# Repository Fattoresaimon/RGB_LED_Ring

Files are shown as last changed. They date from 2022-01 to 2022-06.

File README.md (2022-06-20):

# RGB LED Ring
### This is the official repository of the RGB LED Ring!
### Available on my [DuPPa Store!](https://www.duppa.net/shop/rgb-led-ring/) or [Tindie](https://www.tindie.com/products/saimon/rgb-led-ring-v11/)!

The RGB LED Ring is an accessory of the rotary encoder.
The shaft  of the encoder can be insert in the center hole of the board. It support both the normal rotary encoder and the RGB encoder.

There are 48 RGB LED disposed in a circle with a 40mm diameter. In total there are 144 LEDs.
Each single LED can be controller with 256 step, then each RGB LED are encoded with the 888 format.
The controller is the [ IS31FL3745](https://www.lumissil.com/assets/pdf/core/IS31FL3745_DS.pdf)

In this repository you can find:
- [Schematic](/PDF/)
- [Gerbers](/Hardware/Gerber/)
- [BOM](/Hardware/BOM/)
- [Pick & Place](/Hardware/Pick%20Place/)
- [3D File](/Hardware/ExportSTEP/)

[Here you can find the Arduino library](https://github.com/Fattoresaimon/ArduinoDuPPaLib)

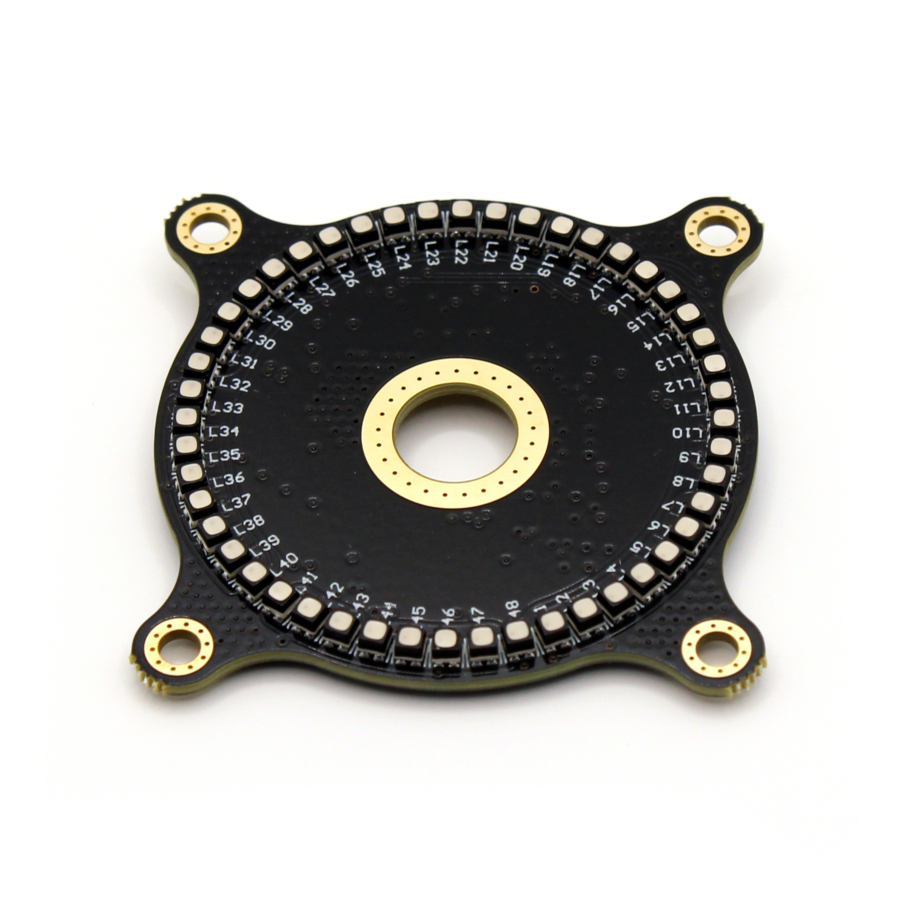
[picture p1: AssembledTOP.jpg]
Assembled


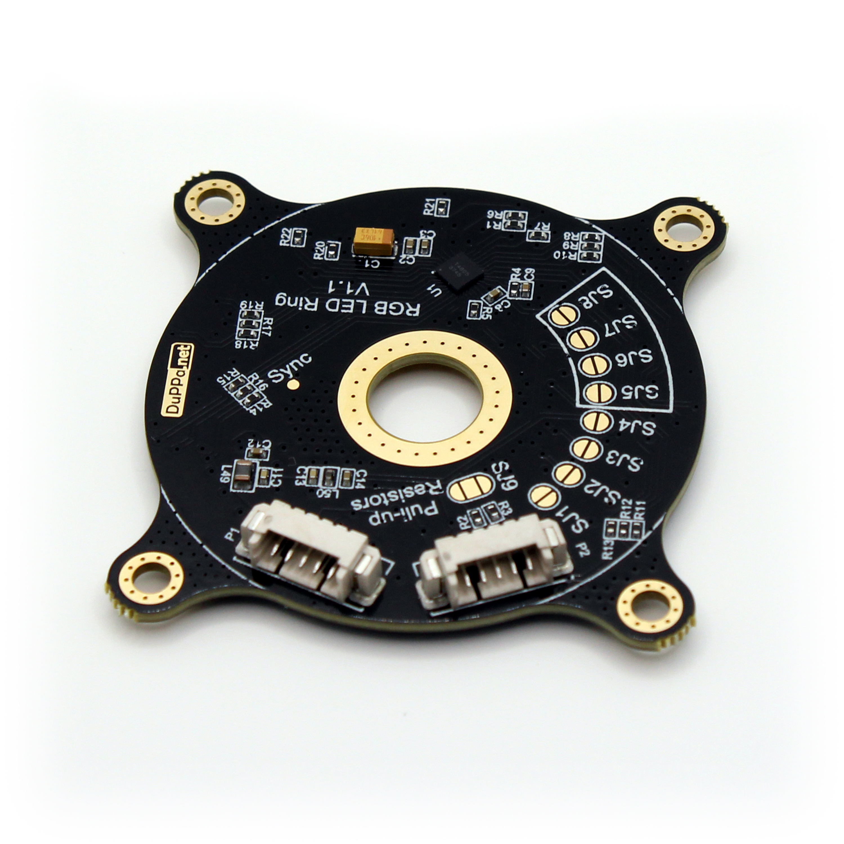
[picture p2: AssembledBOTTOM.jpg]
Bottom


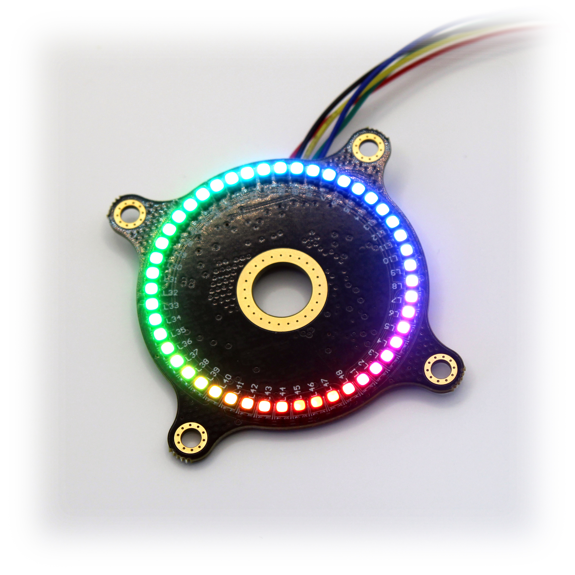
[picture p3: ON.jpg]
ON


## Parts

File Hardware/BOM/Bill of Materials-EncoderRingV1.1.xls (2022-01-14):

Comment | Designator | Footprint | Quantity | Voltage | Value | PartNumber
Tantalum Case-A | C1 | SMC_A | 1 | 16V | 10u | CA45-A016K106T
C-EUC0402 | C2, C8 | C0402 | 2 | 16V | 470n | CL05A474KA5NNNC
C-EUC0402 | C3, C9, C12, C14 | C0402 | 4 | 16V | 100n | CL05B104KO5NNNC
C-EUC0402 | C11, C13 | C0402 | 2 | 16V | 10n | CL05B103KA5NNNC
RGB_2020_NH-Z1921RGBA-SG | L1, L2, L3, L4, L5, L6, L7, L8, L9, L10, L11, L12, L13, L14, L15, L16, L17, L18, L19, L20, L21, L22, L23, L24, L25, L26, L27, L28, L29, L30, L31, L32, L33, L34, L35, L36, L37, L38, L39, L40, L41, L42, L43, L44, L45, L46, L47, L48 | RGB_2121_NH-Z1921RGBA-SG | 48 |  |  | NH-Z1921RGBA-SG
600R@100MHz | L49 | L0805 | 1 |  |  | CBW201209U601T
600R@100MHz | L50 | L0402 | 1 |  |  | CBG100505U601T
Header 5HSMD | P1, P2 | MOLX-52361-0571-5_V | 2 |  |  | C22076
R-EU_R0402 | R1, R8, R11, R14, R17, R20 | R0402 | 6 |  | 51r | RC0402JR-0751RL
R-EU_R0402 | R2, R3, R4 | R0402 | 3 |  | 4k7 | 0402WGJ0472TCE
R-EU_R0402 | R5 | R0402 | 1 |  | 10k | RC-02W1002FT
R-EU_R0402 | R6, R7, R9, R10, R12, R13, R15, R16, R18, R19, R21, R22 | R0402 | 12 |  | 20r | RC0402JR-0720RL
TestPoint Trough Hole | Sync | PAD_1mm | 1 |  |  | RS-200-208
IS31FL3745 | U1 | BGA36C50P6X6_290X290X40 | 1 |  |  | IS31FL3745

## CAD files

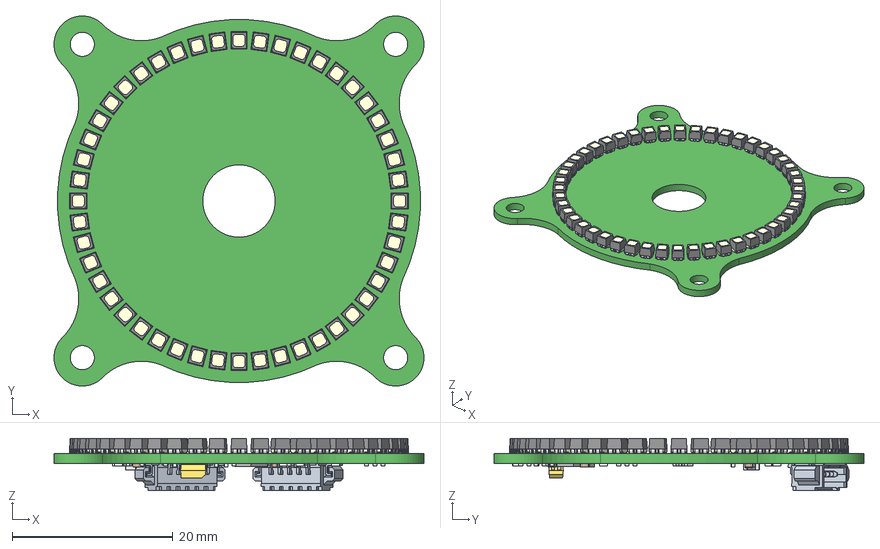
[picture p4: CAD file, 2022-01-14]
Hardware/ExportSTEP/EncoderRingV1.1.step
46.1 x 46.1 x 6.51 mm
User_Library-R_0402 x 22
User_Library-V0402HD_K_X_F6rper_1
User_Library-V0402HD_Anschl_X_FCsse_1
User_Library-FB_2012_Pad001
User_Library-FB_2012_Cut
User_Library-Capacitor_0402 x 8
ASMB-KTF0-0A306--3DModel-STEP-56544 x 48
Extruded

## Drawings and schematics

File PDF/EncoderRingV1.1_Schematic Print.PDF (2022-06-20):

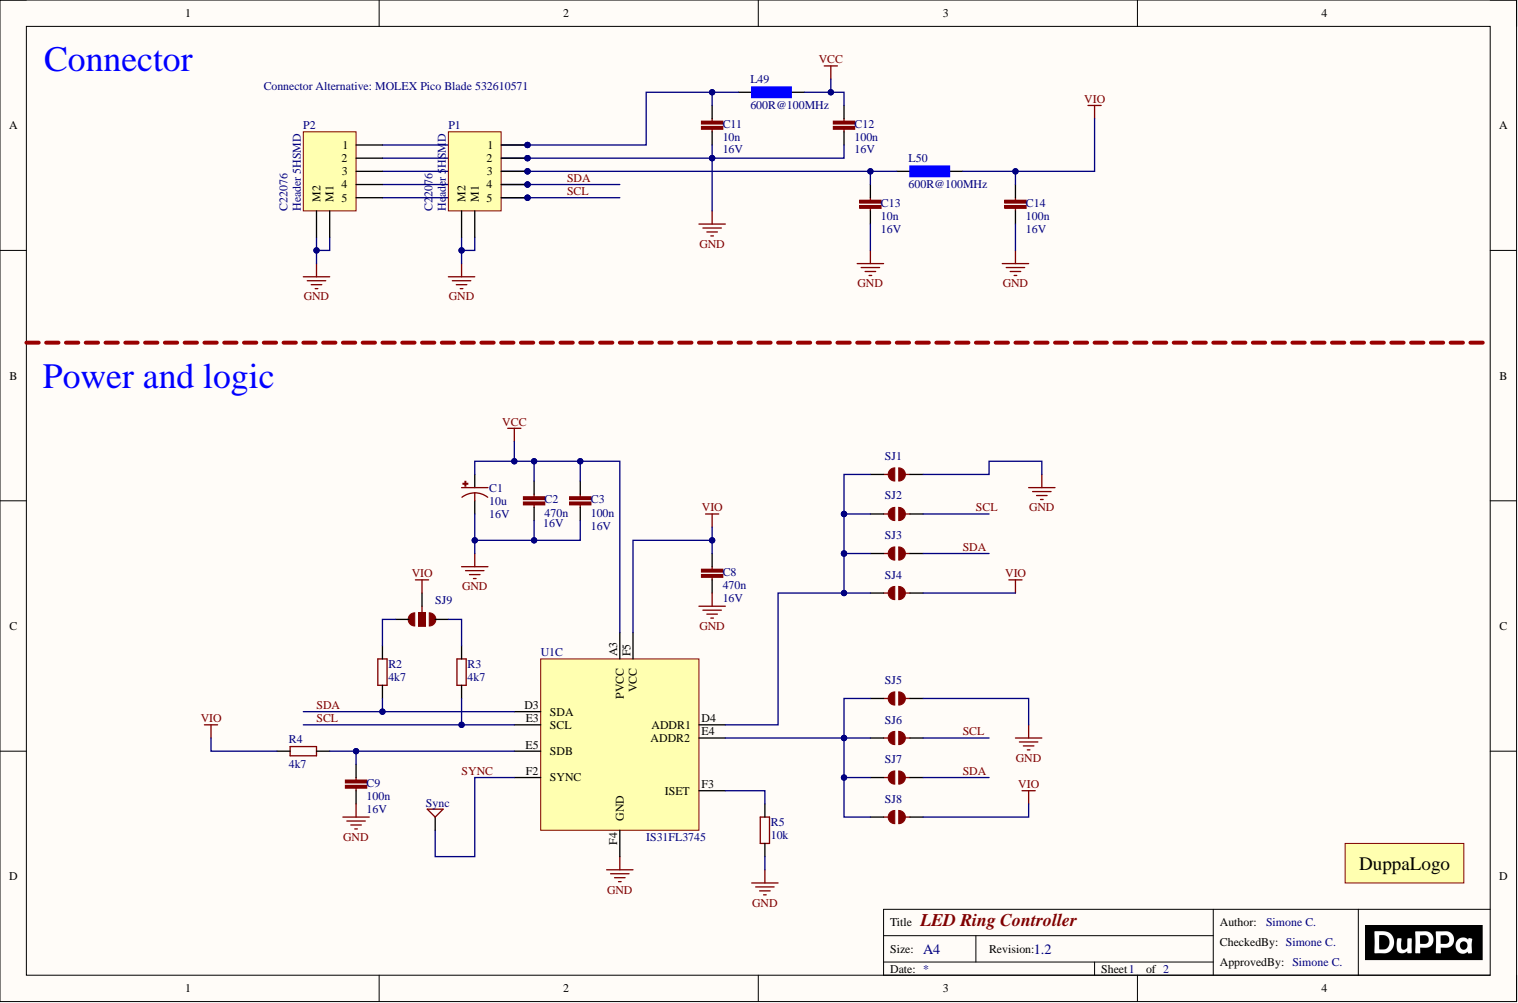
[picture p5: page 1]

Connector Alternative: MOLEX Pico Blade 532610571

SDA

5 | SCL

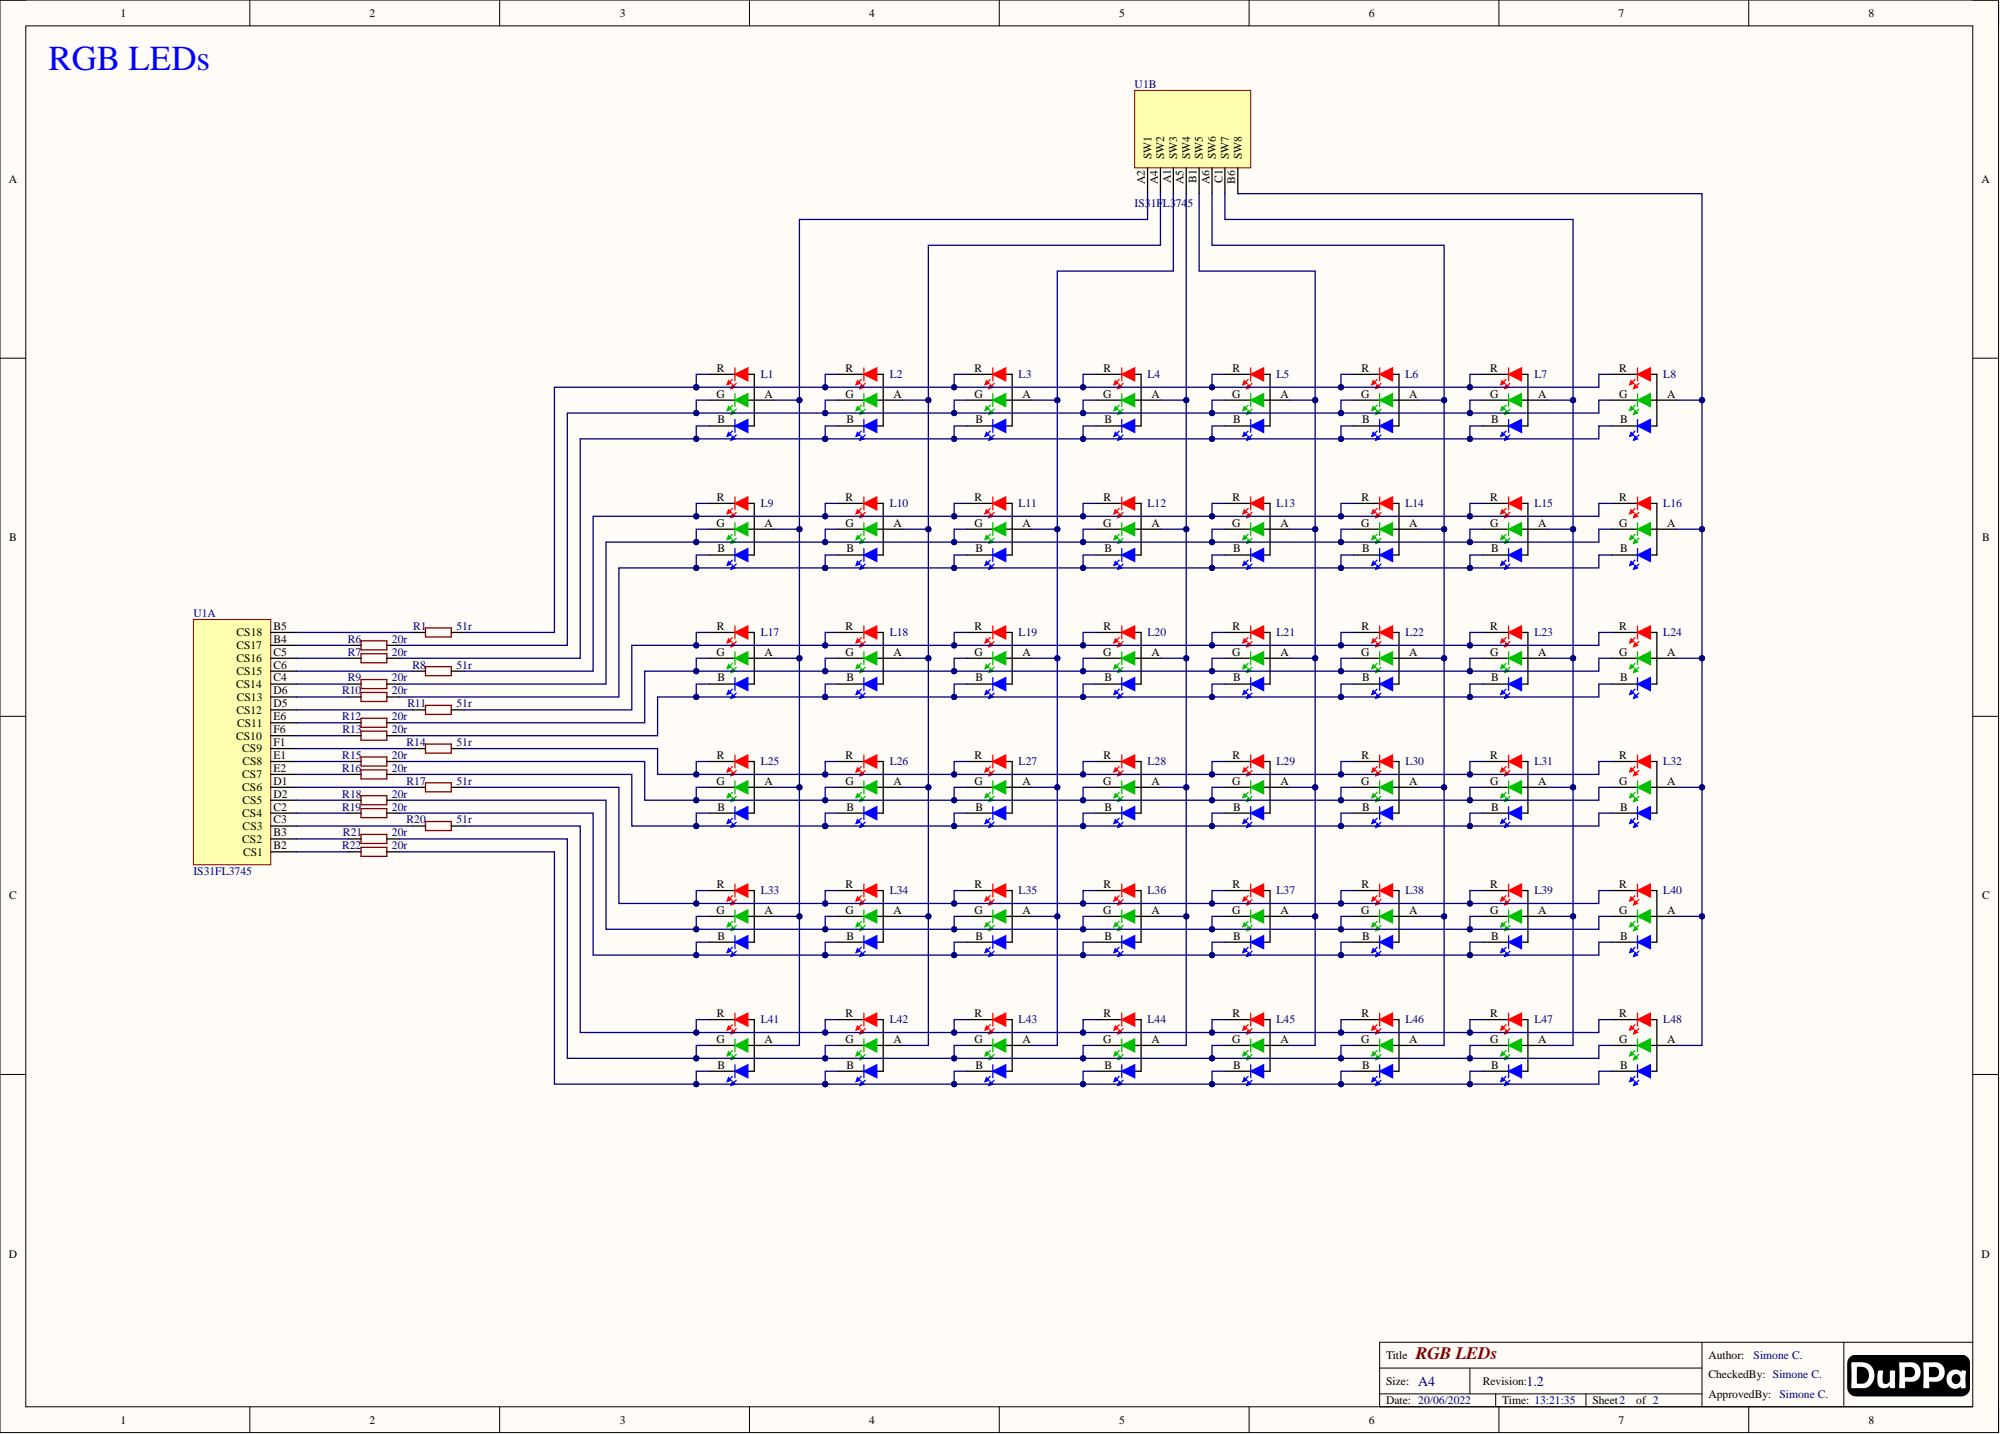
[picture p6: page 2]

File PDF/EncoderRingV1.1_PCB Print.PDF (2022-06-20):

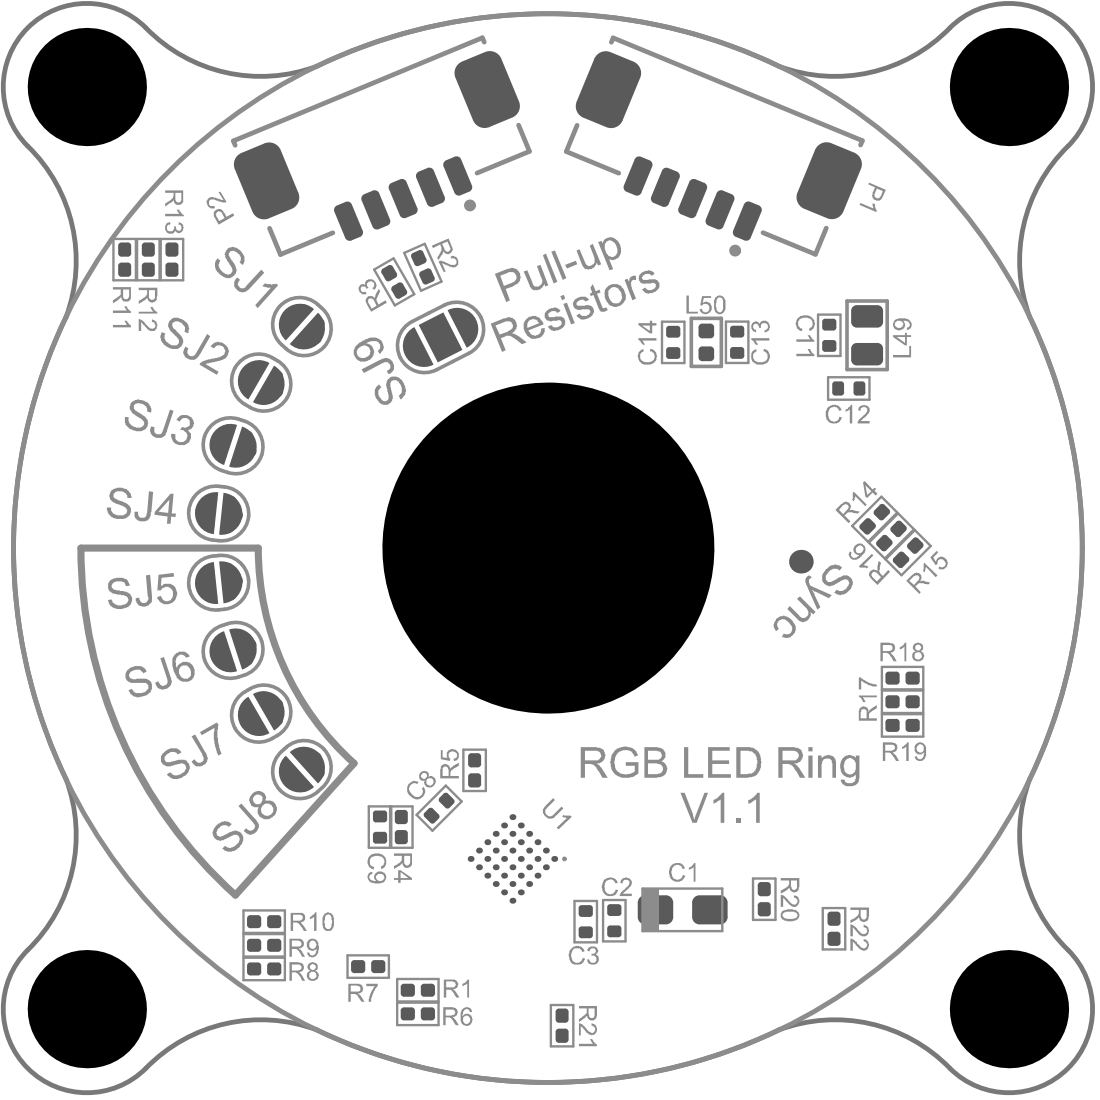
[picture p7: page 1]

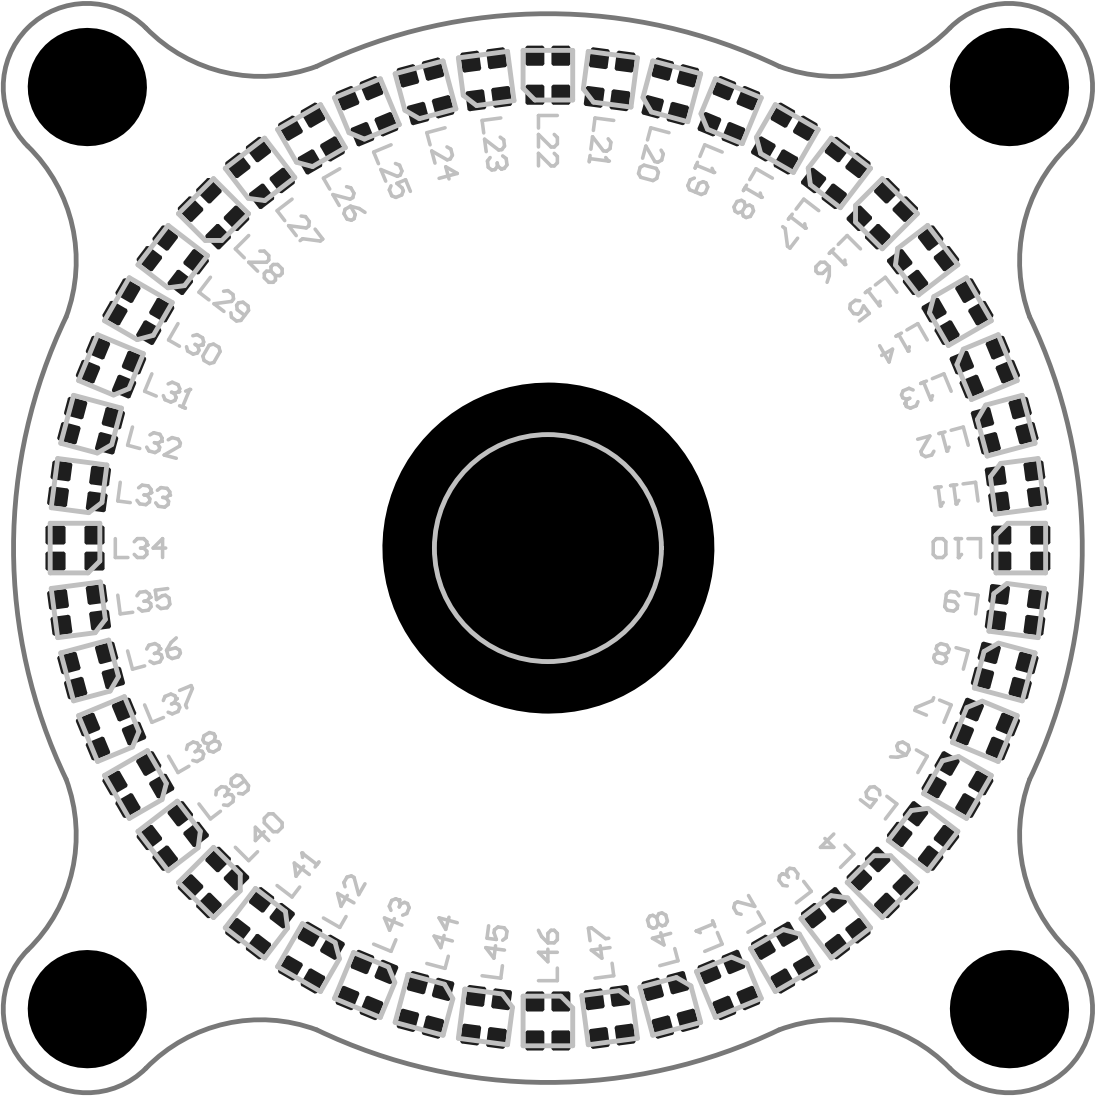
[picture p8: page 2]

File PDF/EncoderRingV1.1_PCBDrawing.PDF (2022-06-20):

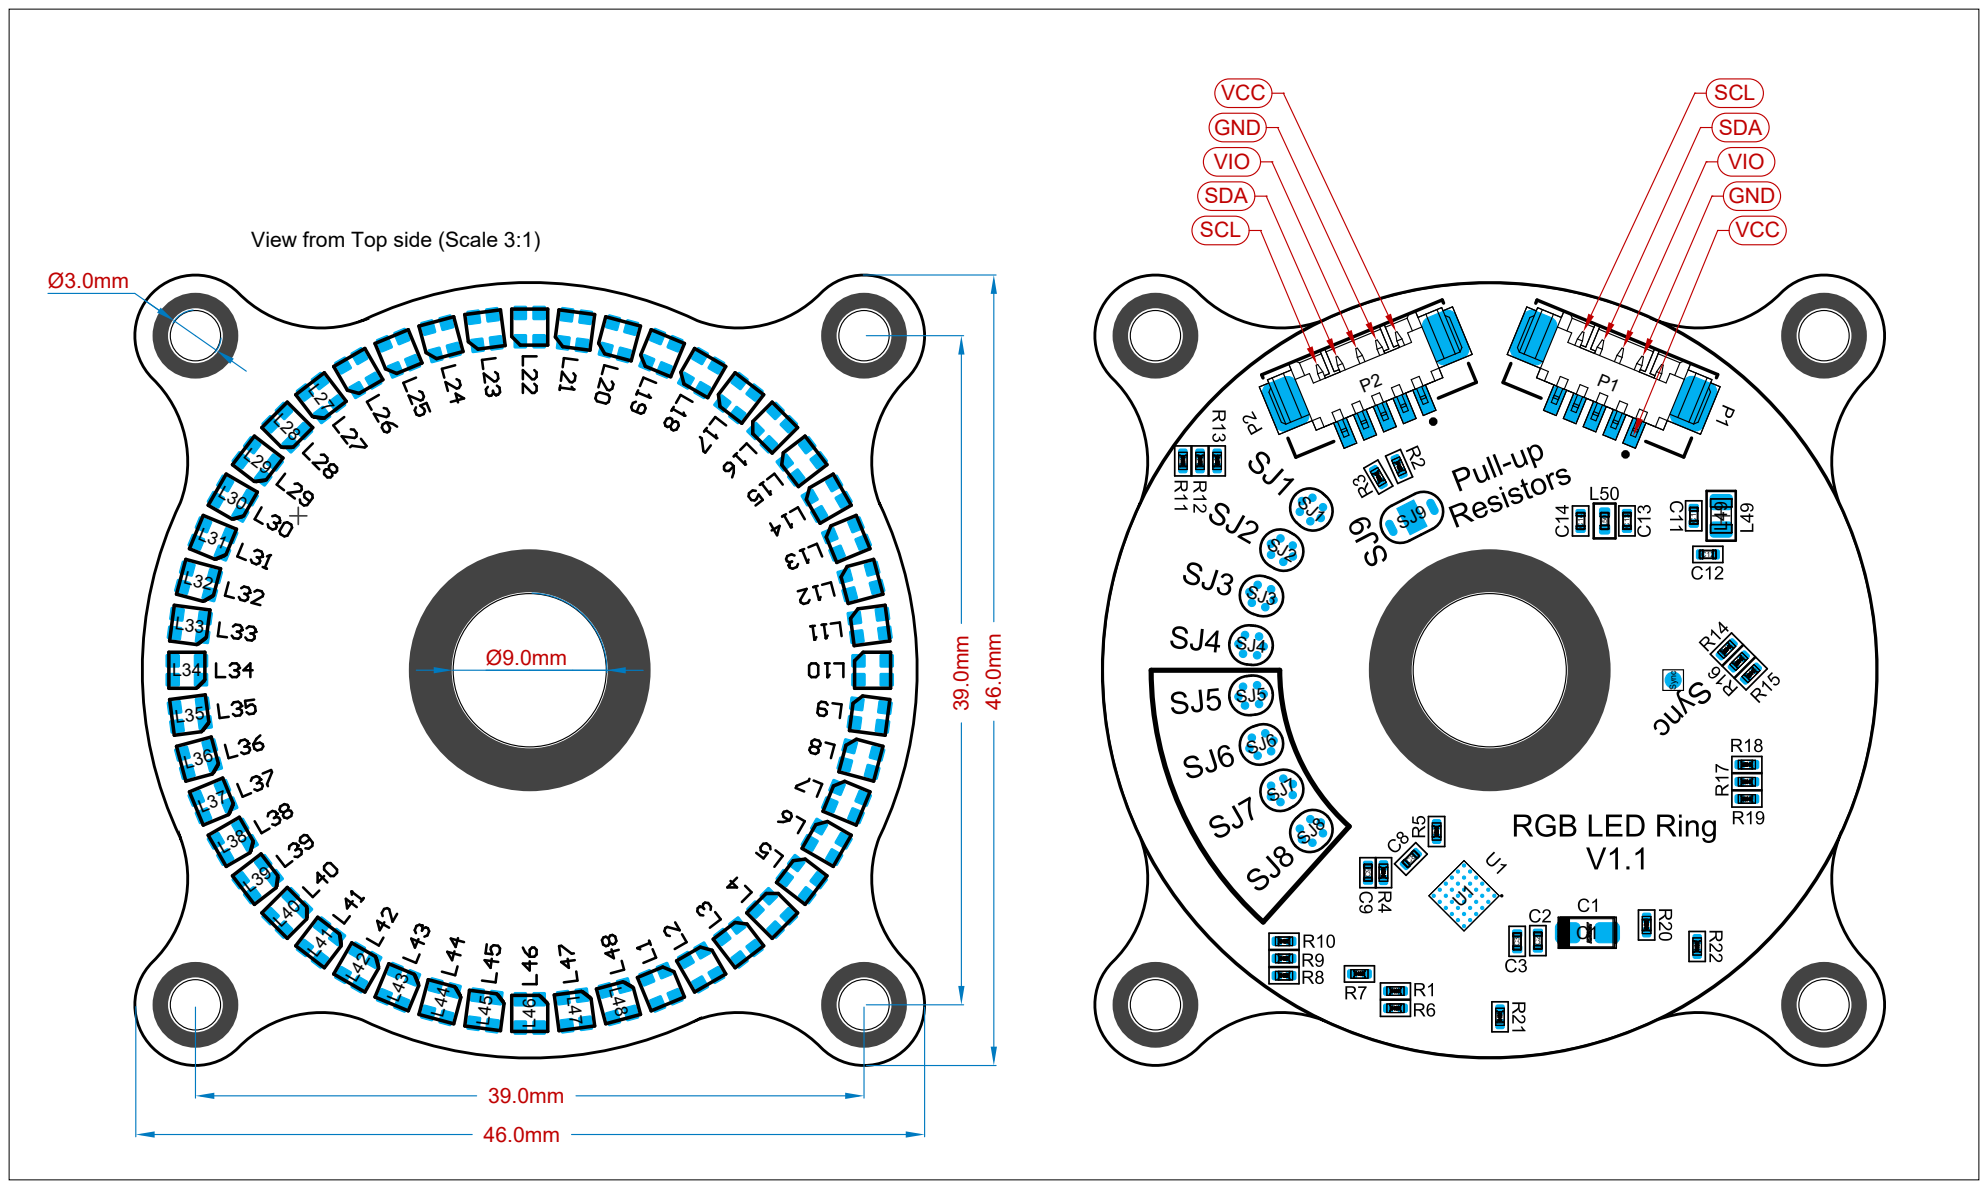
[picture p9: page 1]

View from Top side (Scale 3:1)

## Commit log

2020-09-23 Fixed the wrong PCB thickness
    [EncoderRing.step]
2022-01-14 upgrade to the v1.1
    [Bill of Materials-EncoderRing.csv, Bill of Materials-EncoderRing.xlsx, Bill of Materials-EncoderRingV1.1.xls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]
2022-01-14 changed the folder name
    [EncoderRingV1.1.GBL, EncoderRingV1.1.GBO, EncoderRingV1.1.GBP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]
